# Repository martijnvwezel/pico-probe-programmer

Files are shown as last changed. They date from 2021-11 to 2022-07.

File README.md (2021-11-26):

# pico-probe-programmer
The pico can be used to program other devices. Raspberry pi made such an effort. However there is no board yet, that is open-source and can be used with openocd as a general purpose programmer.

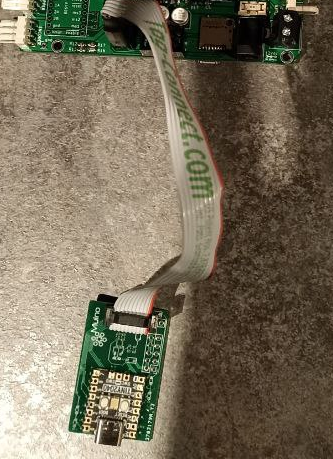
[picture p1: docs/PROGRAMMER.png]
pcb of the pico probe programmer


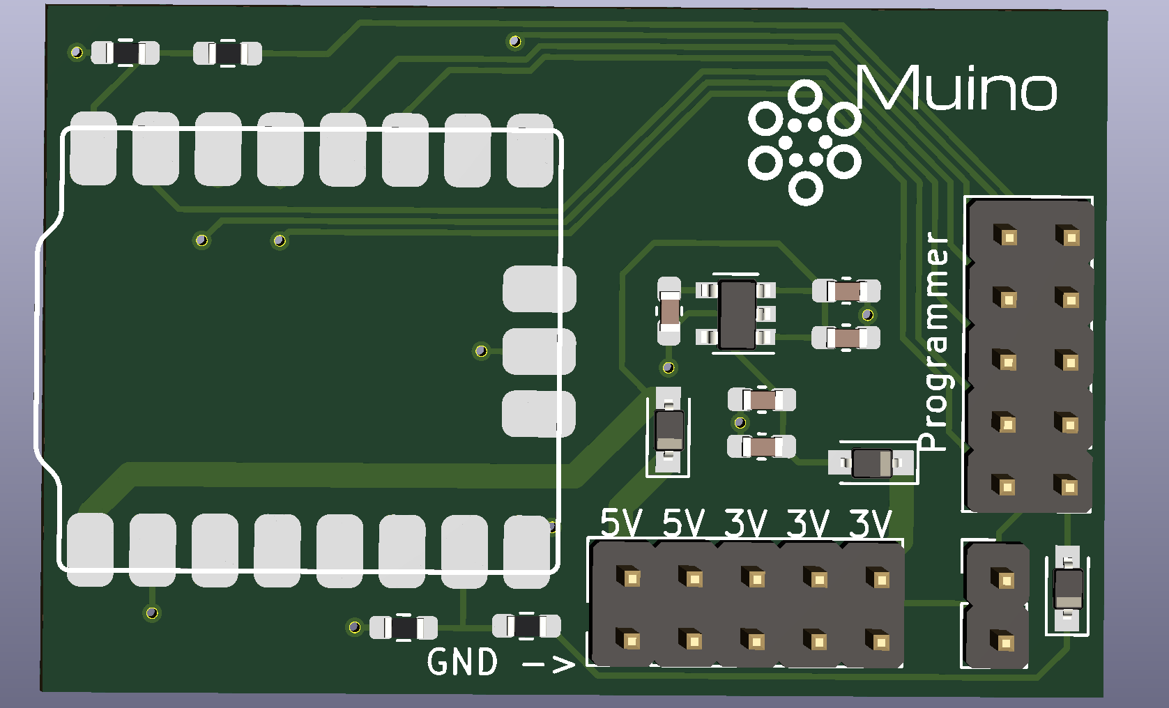
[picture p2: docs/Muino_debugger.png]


# Why Probe and not segger jlink?
Segger Jlink bugged me because I am using a Jlink at home, and it's not compatible anymore with the newest generation of Cortex chips. Another issue that I made, I don't make them that often, but if I do I want my debugger to be able to change the pinout, like an RX, TX swap. In one of the boards, I made somehow SWO and Rx got on the wrong pin, using the pico probe I could change the location of the pins and everything worked fine :).

```bash 
# Change the pins : pico-probe/src/picoprobe_config.h
# Build:
cd pico-probe
mkdir build/
cd build/
cmake ..
make -j
# Connect the picoprobe, pressing the boot button
# it shows a folder and place the file picoprobe.uf2 from the build folder
# Updated picoprobe
# for windows see docs/windows-install.md
``` 

pi nchange
  
> Smalle note: the Tx 5 is not usable in this example. I didn't need it anyway.

# A quick order ordering
Take a PCB maker like JLCPCB. Use the all the files from the `pcb-readyto-order/`, the Bom fils is not needed for that, but there is a list of the different type of components. The complete list needs to be updated soon. When I finally understand the BOM generation of Kicad. See tempory list below under *Design choice* chapter.

# What software is needed?
The software found in the submodules. I also added the pico-sdk to it, for code compatibility.
``` bash
cd pico-probe-programmer/
git submodule update --init 
```

Then go to the folder `pico-probe`, run the commands:
```bash
mkdir build/
cd build/
cmake ..

```

This will generate `picoprobe.uf2`. Or use the prebuild file: `binaries/picoprobe.uf2`. I prebuild this file, so I can quickly update it to a programmer if I need it again.

# Design choice
I like to use the [Pogo style adapter](https://www.tag-connect.com/info). For work and hobby projects it saves a head to solder, and the PCB looks more cleaner. Sometimes I need a 3V3 power pin or 5V power pin so I added an extra header for it. If you are not interested in the 3V3 or want to save componentens? The schema part 3V3 supply does not need to be added to the pcb. Actually, the PIM558 and the programmer header are madetory.
For custom program headers I added the possiblity to add 5V to pin 5 of the programmer header to disable power to the board that needs to be programmed. For my own custom boards I use the 5V to directLy power purposes.

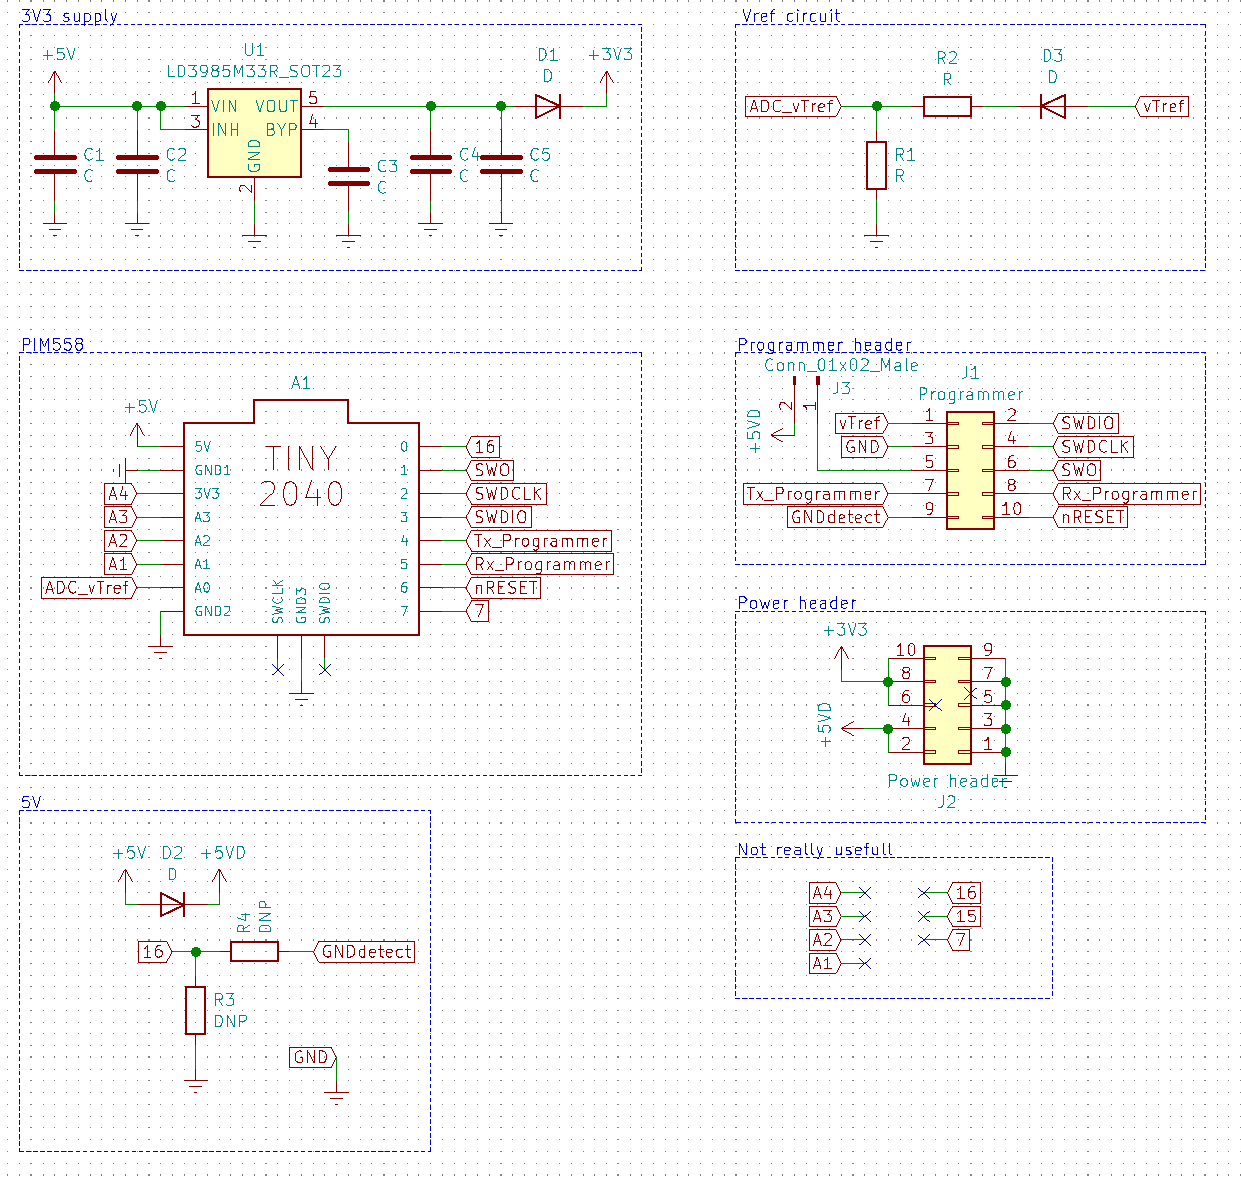
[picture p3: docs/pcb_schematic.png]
Schematic of the PCB


List of values, soon to be added to the schematics
* C1: 1UF
* C2: 100nF
* C3: 10nF
* C4: 4.7uF
* C5: 100nF
* R1: 10K
* R2: 100
* d1,2,3: BAT60JFILM
* 2.54mm male headers 02x05
* A1: PIM558 - Tiny 2040
* U1: LD3985M33R

In the future I want to add some extra features like read voltage of target and detection of GND. Though making it a pull-up (internally in the 2040), and read the voltage on the pin. The voltage read is what Segger-Jlinks do to detect voltage issues on target board.

# Layout
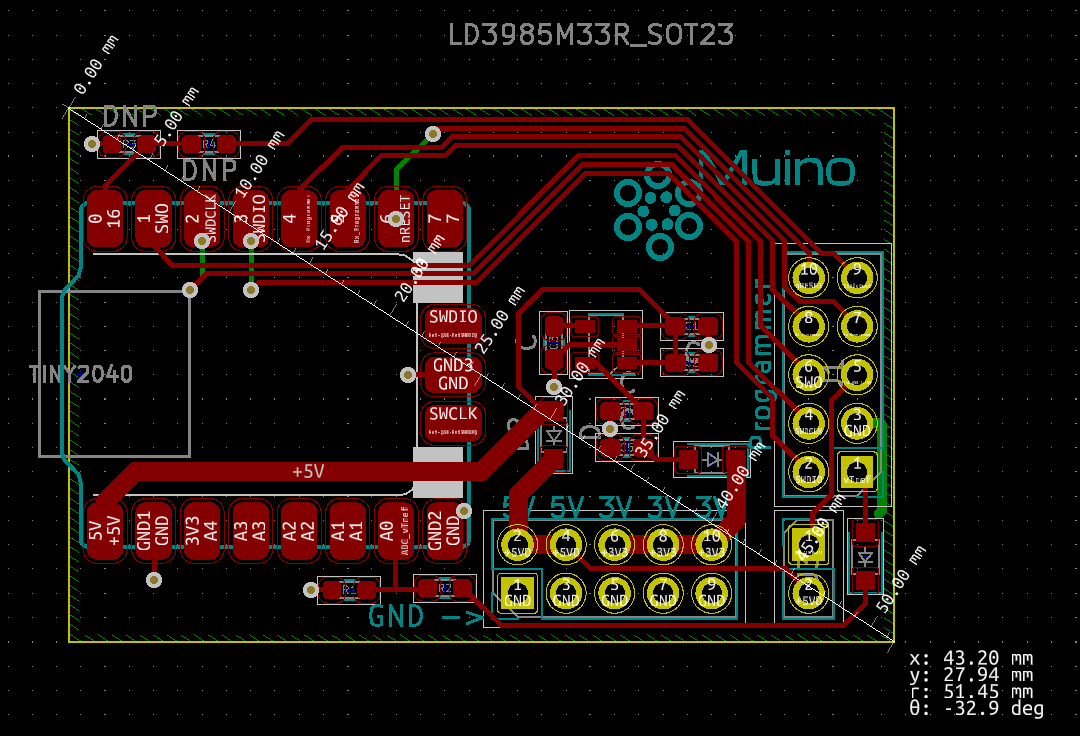
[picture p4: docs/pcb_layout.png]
Layout of the PCB


# Enclosure
The enclosure is quickly made in Freecad with my 3D printer. I need to calibrate the heatbed again so it looks less good using my 3D printer, but it was printed in ~10min, with my help pressing down the print to the bed.  
The main goal of the print was to protect the pins under the PCB.   
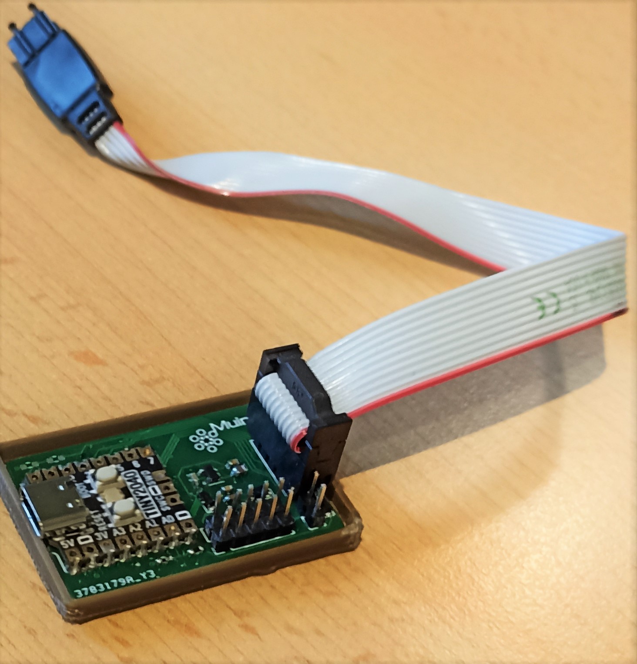
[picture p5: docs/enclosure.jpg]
Enclosure of the PCB


# Hardware licence 
The hardware is licensed under [CERN-OHL-S v2](https://cern.ch/cern-ohl).

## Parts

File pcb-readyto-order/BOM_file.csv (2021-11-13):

Id | Designator | Package | Quantity | Designation | Supplier and ref
1 | J3 | PinHeader_1x02_P2.54mm_Vertical | 1 | Conn_01x02_Male
2 | G1 | Suino | 1 | LOGO
3 | D2,D3,D1 | D_SOD-323_HandSoldering | 3 | D
4 | R4,R3 | R_0603_1608Metric_Pad0.98x0.95mm_HandSolder | 2 | DNP
5 | U1 | SOT-23-5 | 1 | LD3985M33R_SOT23
6 | R2,R1 | R_0603_1608Metric_Pad0.98x0.95mm_HandSolder | 2 | R
7 | J2 | PinHeader_2x05_P2.54mm_Vertical | 1 | Power header
8 | C5,C4,C3,C2,C1 | C_0603_1608Metric_Pad1.08x0.95mm_HandSolder | 5 | C
9 | J1 | PinHeader_2x05_P2.54mm_Vertical | 1 | Programmer
10 | A1 | TINY2040 | 1 | TINY2040 | PIM-558

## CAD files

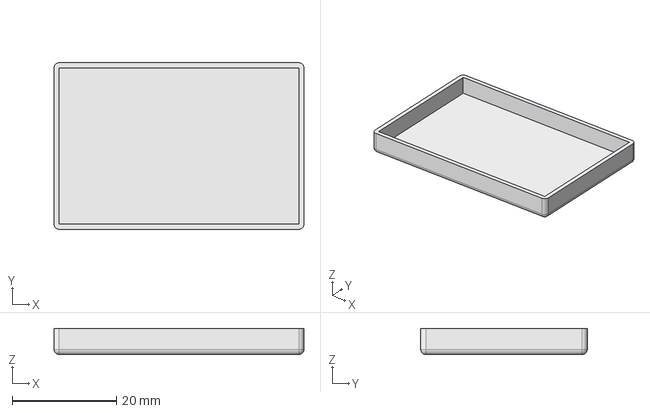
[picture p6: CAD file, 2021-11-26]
enclosure/enclosure.FCStd
48.0 x 32.0 x 5.00 mm

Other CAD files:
enclosure/enclosure-BodyThickness.stl

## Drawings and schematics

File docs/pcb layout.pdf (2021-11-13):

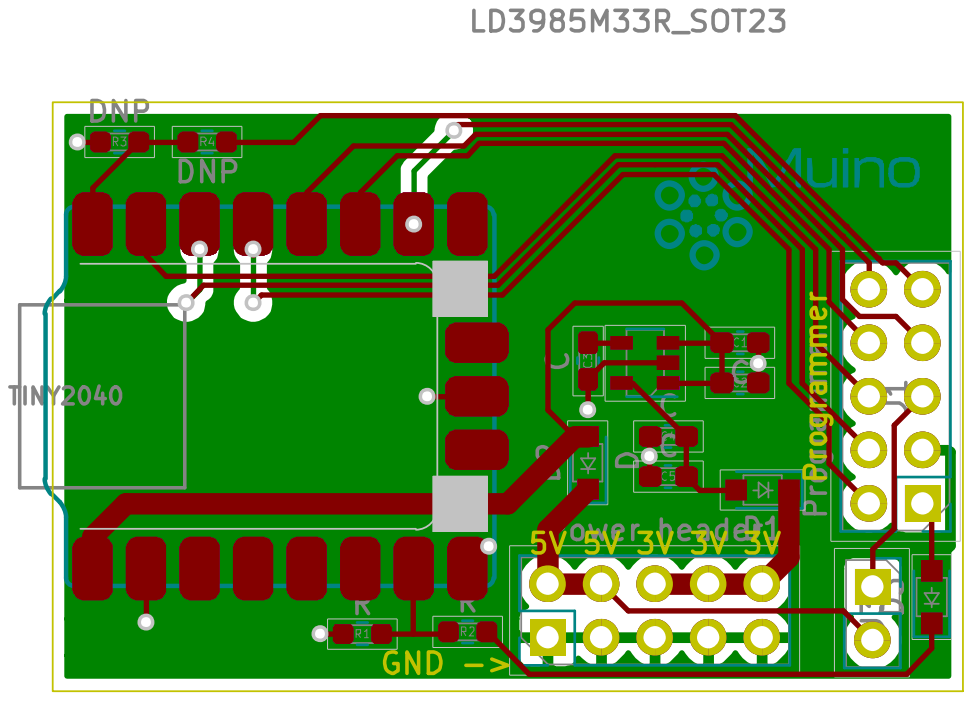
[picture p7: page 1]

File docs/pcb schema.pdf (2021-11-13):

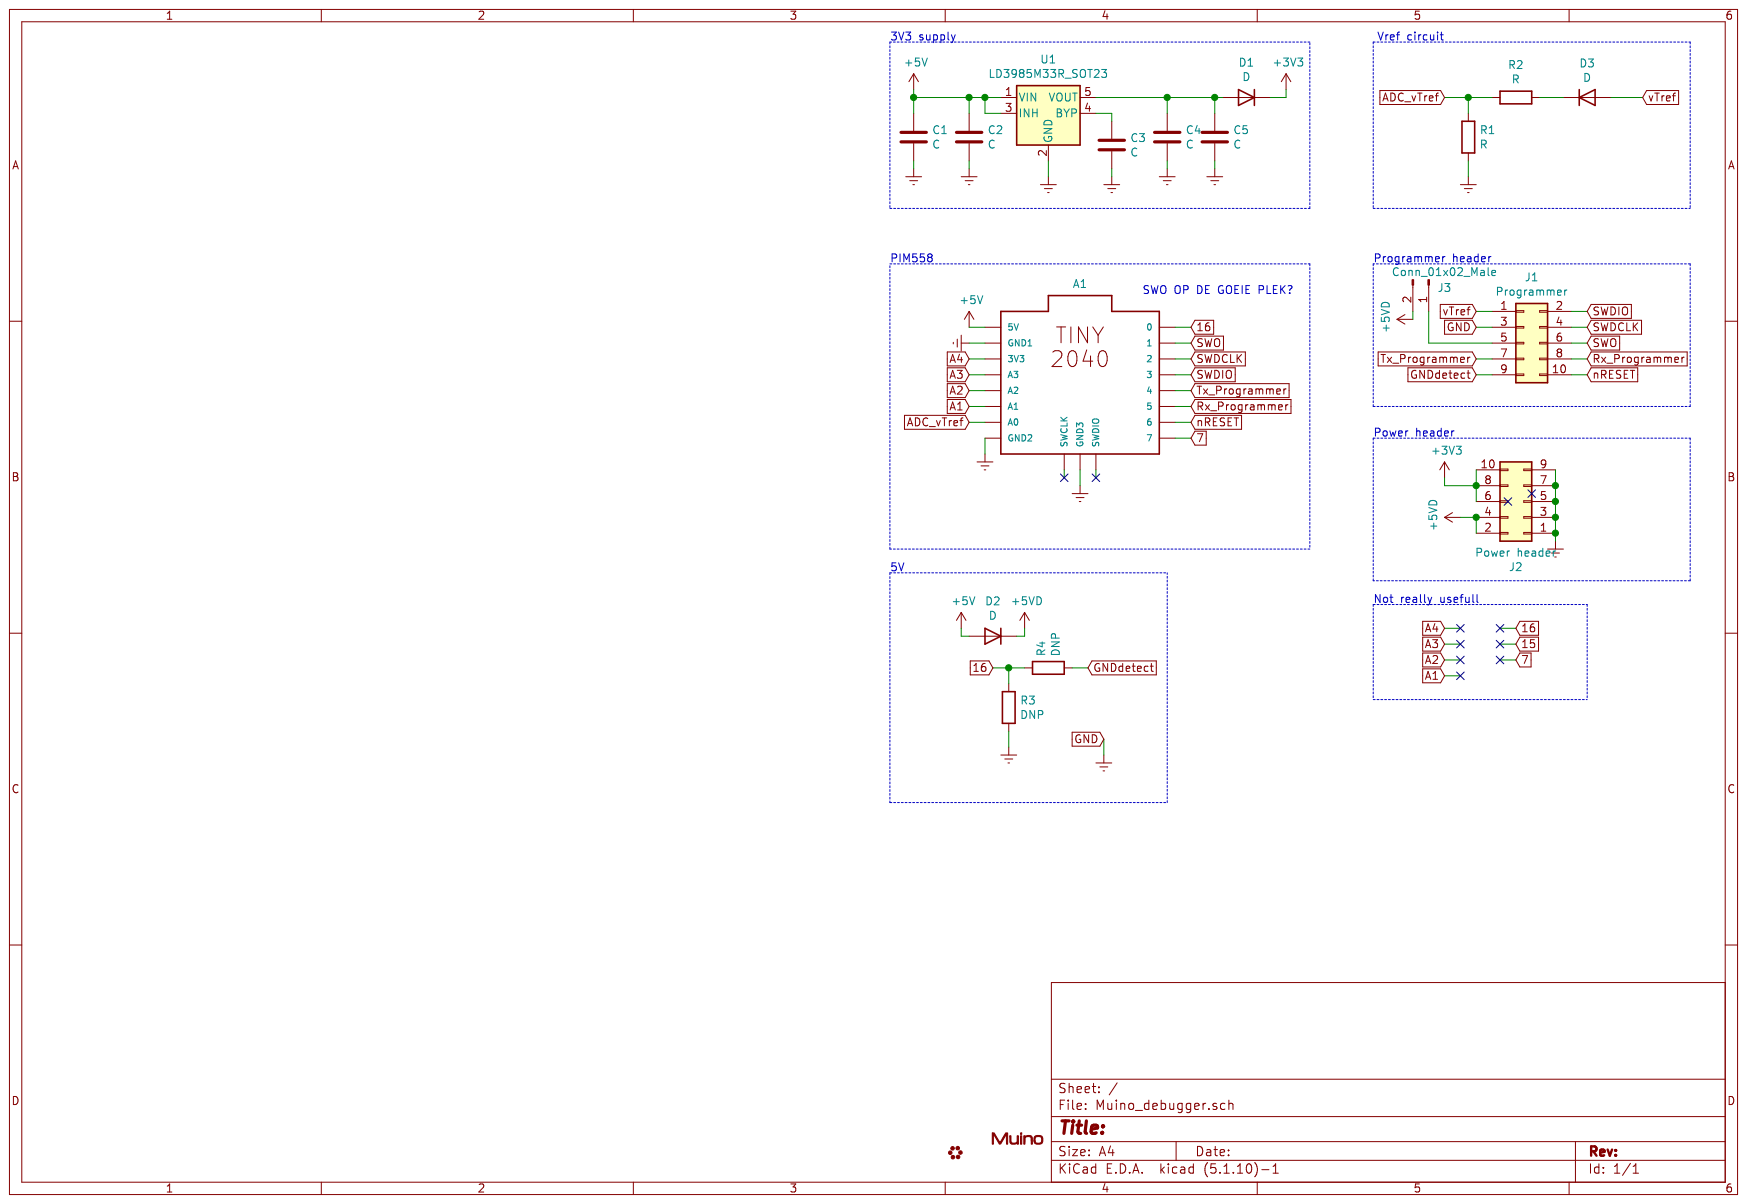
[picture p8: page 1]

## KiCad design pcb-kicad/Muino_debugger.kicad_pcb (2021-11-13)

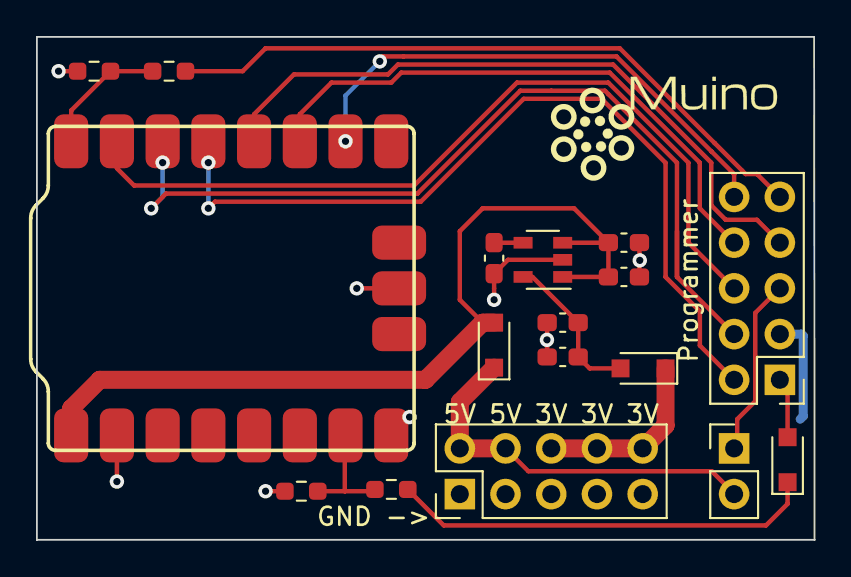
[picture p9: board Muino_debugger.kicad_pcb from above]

Board: 2 copper layers, 43.2 x 27.9 mm, 18 parts (0 on the bottom side), 18 nets.

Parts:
A1: TINY2040
C1, C2, C3, C4, C5: C; C_0603_1608Metric_Pad1.08x0.95mm_HandSolder
D1, D2, D3: D; D_SOD-323_HandSoldering
G1: LOGO; Suino
J1: Programmer; PinHeader_2x05_P2.54mm_Vertical
J2: Power header; PinHeader_2x05_P2.54mm_Vertical
J3: Conn_01x02_Male; PinHeader_1x02_P2.54mm_Vertical
R1, R2: R; R_0603_1608Metric_Pad0.98x0.95mm_HandSolder
R3, R4: DNP; R_0603_1608Metric_Pad0.98x0.95mm_HandSolder
U1: LD3985M33R_SOT23; SOT-23-5

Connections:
16: A1.0, R3.1, R4.1
+3V3: D1.1, J2.6, J2.8, J2.10
+5V: A1.5V, C1.1, C2.1, D2.2, U1.1, U1.3
+5VD: D2.1, J2.2, J2.4, J3.2
ADC_vTref: A1.A0, R1.1, R2.2
GND: A1.GND1, A1.GND2, A1.GND3, C1.2, C2.2, C3.2, C4.2, C5.2, J1.3, J2.1, J2.3, J2.5, J2.7, J2.9, R1.2, R3.2, U1.2
GNDdetect: J1.9, R4.2
unnamed: C3.1, U1.4
unnamed: C4.1, C5.1, D1.2, U1.5
unnamed: D3.1, R2.1
unnamed: J1.5, J3.1
Rx_Programmer: A1.5, J1.8
SWDCLK: A1.2, J1.4
SWDIO: A1.3, J1.2
SWO: A1.1, J1.6
Tx_Programmer: A1.4, J1.7
nRESET: A1.6, J1.10
vTref: D3.2, J1.1

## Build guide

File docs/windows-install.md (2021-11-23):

# Windows install - example with RPi Pico

## Step 1
Download the [Zadig USB tool](https://zadig.akeo.ie/) and select the Picoprobe and libusb-win32.
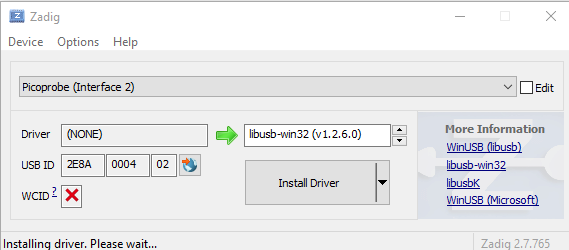
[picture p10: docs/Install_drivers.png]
Layout of the PCB


## Step 2
Follow the tutorial [digikey-tutorial](https://www.digikey.nl/en/maker/projects/raspberry-pi-pico-and-rp2040-cc-part-2-debugging-with-vs-code/470abc7efb07432b82c95f6f67f184c0) you can download the OpenOCD toolchain, that is already being build. I can add this to this repo if people need that. This however, only works in Git Bash or MinGW environments.

## Step 3 
Add the paths to the system, you should restart `git-bash` always fully, so all windows should be closed, or just reboot just to be sure. The following are the paths:  

### add to the path
windows env UGH
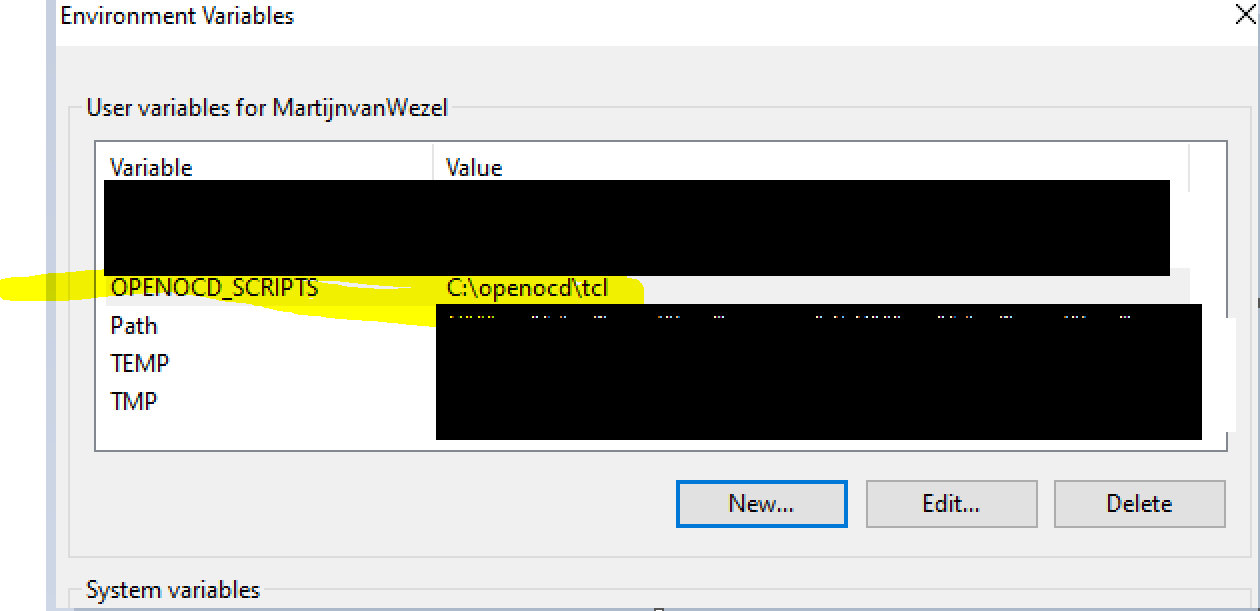
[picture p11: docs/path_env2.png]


* `OPENOCD_SCRIPTS` -> with value `env
` 
* `Path` -> add the following `C:\openocd\src`

### without changing the paths
A without the env solution, you can use the `-s` option:
``` bash
openocd -f interface/picoprobe.cfg -f target/rp2040.cfg -s /c/openocd/tcl/
``` 

## Step 4
Validate if everythings works fine
``` bash
openocd -f interface/picoprobe.cfg -f target/rp2040.cfg
``` 
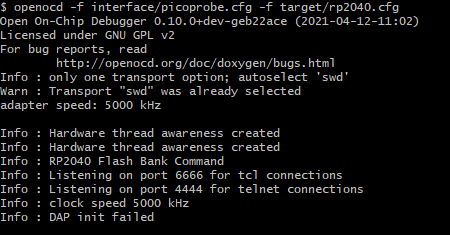
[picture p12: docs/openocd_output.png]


The DAP init failed means that it didn't correctly connect with the device that you want to connect to. Check the cables or connections to the pins.

## Step 5
Make your life easier to add a `picoprobe.bat` in the `src/` folder of the `openocd/src/picoprobe.bat`
With the following information:
``` shell
openocd.exe -s ./tcl -f interface/picoprobe.cfg -f target/rp2040.cfg -f listen-all.cfg
```
Then you only have to type .picoprobe.bat in a terminal. 

## LISTEN-ALL.CFG
If you prefere to run it as an server you need the listen-all.cfg config. For the use PlatformIO tool this is needed.

# Happy programming/debugging.

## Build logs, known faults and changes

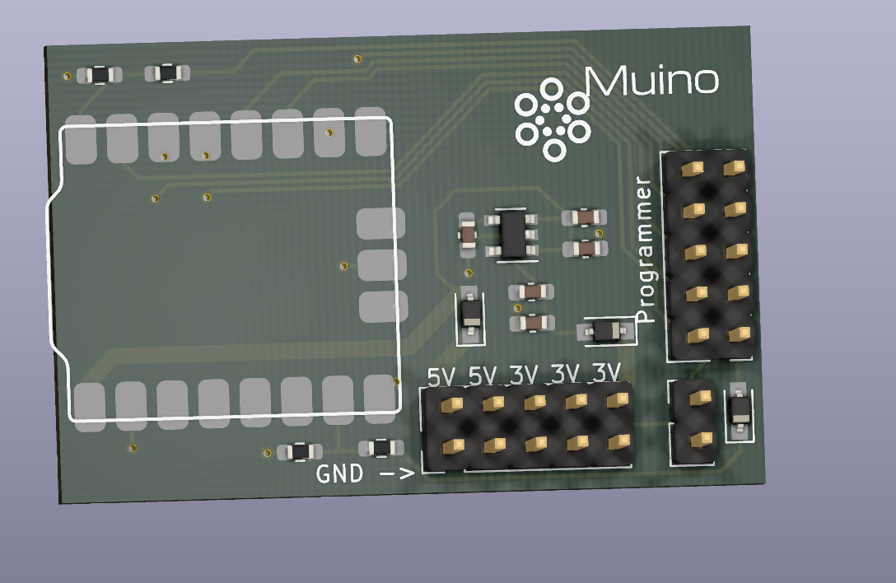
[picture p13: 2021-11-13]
docs/Muino_debugger_shadow.png

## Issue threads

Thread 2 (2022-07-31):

how to change swd pins

hmz06967, 2022-07-31:
picoprobe's swd 2 and 3 io pins, but I want these pins 6 and 7, is it possible? Also, when compiling it myself, if the utf size is 76kb, where am I going wrong with 50kb?
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

martijnvwezel, 2022-07-31:
Should be possible, don't see a reason why not. If you changed them in the pin header, you compile it and you can drag the `.uf2` file to the storage of the pico. You are not doing anything wrong it's the way `.uf2` works. It contained more information etc.

hmz06967, 2022-07-31:
Thank you, please can you changed pins 2 and 3 to toher pins and after building your pcb make send me uf2? Do you can a for me?

martijnvwezel, 2022-08-03:
I am currently not close to my computer: the only change you need to do is the following :
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

hmz06967, 2022-08-04:
Thank you

martijnvwezel, 2022-08-04:
And you have to change the
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
 to some pin you like

Closed 2022-08-14.

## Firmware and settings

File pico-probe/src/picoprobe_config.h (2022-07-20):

/*
 * The MIT License (MIT)
 *
 * Copyright (c) 2021 Raspberry Pi (Trading) Ltd.
 *
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
 */

#ifndef PICOPROBE_H_
#define PICOPROBE_H_

#if false
#define picoprobe_info(format,args...) printf(format, ## args)
#else
#define picoprobe_info(format,...) ((void)0)
#endif


#if false
#define picoprobe_debug(format,args...) printf(format, ## args)
#else
#define picoprobe_debug(format,...) ((void)0)
#endif

#if false
#define picoprobe_dump(format,args...) printf(format, ## args)
#else
#define picoprobe_dump(format,...) ((void)0)
#endif


// PIO config
#define PROBE_SM 0
#define PROBE_PIN_OFFSET 2
#define PROBE_PIN_SWCLK PROBE_PIN_OFFSET + 0 // 2
#define PROBE_PIN_SWDIO PROBE_PIN_OFFSET + 1 // 3

// Target reset config
#define PROBE_PIN_RESET 6

// UART config
#define PICOPROBE_UART_TX 5
#define PICOPROBE_UART_RX 1
#define PICOPROBE_UART_INTERFACE uart0
#define PICOPROBE_UART_BAUDRATE 256000 //default: 115200 // max: 921600

// LED config
#ifndef PICOPROBE_LED

#ifndef PICO_DEFAULT_LED_PIN
#error PICO_DEFAULT_LED_PIN is not defined, run PICOPROBE_LED=<led_pin> cmake
#elif PICO_DEFAULT_LED_PIN == -1
#error PICO_DEFAULT_LED_PIN is defined as -1, run PICOPROBE_LED=<led_pin> cmake
#else
#define PICOPROBE_LED PICO_DEFAULT_LED_PIN
#endif

#endif

#endif

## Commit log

2021-11-13 First version commit
    [BOM_file.csv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]
2021-11-13 Adding pico probe from official Raspberry pi
2021-11-24 Freecad desgin - start of design.
    [enclosure.FCStd]
2021-11-26 Adding enclosure however it is a big too big.
    [enclosure-BodyThickness.stl, enclosure.FCStd]
2021-11-26 Removing the pico-probe submodule
2022-07-20 Adding rx tx swap
    [picoprobe_config.h]
